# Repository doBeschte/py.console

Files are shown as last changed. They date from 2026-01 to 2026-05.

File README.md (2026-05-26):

# py.console
A gaming console based on a Raspberry Pi 5 and python games with 5 bluetooth-controllers
I designed the 3D-printed parts in Fusion360, the schematics and the PCB in KiCAD.

# HARDWARE

## CONSOLE

Console rendering

The console is based on a Raspberry Pi 5. The 3D-printed housing (12cm x 12cm) includes two parts. The main part holds all the components and electronics.
The top view looks like this:
Bildschirmfoto 2026-01-09 um 21 03 50

On the left side of this picture the Raspberry Pi will be mounted using four pieces that fit into its mounting holes. The HDMI-Ports and the USB-C-Ports are accessible from the back side of the console.
On the sides I designed some holes for the air outlet of the device. 
Bildschirmfoto 2026-01-09 um 20 36 10

On the front are two holes for a USB port and a boot push button. 
The USB port is connected to the USB port of the Raspberry Pi. It will be used to connect a USB stick with the .py game files.
The wires of the push button are connected to the two pins next to the battery connector on the Raspberry Pi to act like the integrated button.
The button has an integrated LED that is connected to GPIO13 with a resistor in series to be enabled when the device is operating.
An active buzzer is connected to GPIO18 to make a sound when booting or starting a game. It is placed in the hole of the case.

The other housing part is the top cover.
Bildschirmfoto 2026-01-09 um 21 09 07

It is mounted with two screws on the front and round pieces that fit into holes in the main part at the back.
Bildschirmfoto 2026-01-09 um 21 11 52

I will use the Raspberry Pi active cooler that takes air through the holes in the top cover.

https://github.com/user-attachments/assets/2c3ed64f-fc42-457b-9e3d-2fc4b27291a0

*This video shows how the mounting will work*

## CONTROLLERS

The controllers are more complicated as they are smaller and include more components.
I build five of them because a lot of things are shipped in five or ten, including PCBs, Joysticks, buttons, batteries etc. .

Bildschirmfoto 2026-01-14 um 21 28 14

The rendering doesn't include the joystick because I don't print it by myself.

Bildschirmfoto 2026-05-26 um 19 56 19

Bildschirmfoto 2026-01-06 um 15 12 12

The microcontroller is a XIAO-ESP32-C3 that has BLE and a battery charger and it is small. Its USB-C port is the charging port of my controller.

At the left side is a tipical thumb joystick and at the right side two buttons. They are connected to inputs on the ESP32 and GND.
Around the PCB are 20 "PL9823" LEDs. They need 5 volts which the ESP32 doesn't deliver. So, I use a little boost converter from the battery cell to five volts and a 74125 level shifter (with a 330Ω resistor) for the data. A MOSFET turnes the boost converter off when the ESP32 is in DeepSleep.
Two capacitors deliver high current for the LEDs for a short time.
The battery voltage is measured by splitting it in half using two resistors 1MΩ

The device is 12cm x 5cm, rounded at the sides and around 26mm thick. The case is made like the one of the console, but the cover is at the opposite side. The PCB is held between these two parts.
The main part holds the battery in the middle and the "keycaps" at the right side OF THE DEVICE.
Bildschirmfoto 2026-01-06 um 18 56 03

The "keycaps" just fit into their holes and have a margin to prevent falling out.
Bildschirmfoto 2026-01-06 um 18 56 38

The cover is screwed into the main case at the sides. It holds the PCB at the edges, under the joystick and under the keys for pressure, leaving a bit of space for the solder joints.

The PCB in my Renderings does not already contain all of the parts and some are just visible as pin headers:

Bildschirmfoto 2026-05-26 um 20 54 24

The following picture shows the mounted PCB inside the case. It might look wrong at the sides (little space) but it isn't.

Controller Rendering

## BOM

CONSOLE:

• Raspberry Pi 5, 4GB RAM  -  / 

• Power supply for Pi 5  -  / 

• Raspberry Pi 5 active cooler  -  /

• USB-A port  -  /

• push button, 16mm mounting hole  -  /

• active buzzer, 24mm Ø  -  /

• 330Ω resistor  -  /

• microSD-card  -  /

TOTAL PRICE CONSOLE: / (I will buy everything by myself)

CONTROLLERS:

• 5pcs custom PCB, 112mm*46mm  -  5,16€

• 5pcs Seeed Studio XIAO-ESP32-C3  -  33,33€

• 5pcs thumb joystick  -  0,87€

• 10pcs silent push button, 8*8mm  -  5,62€

• 10pcs LiPo battery, 30mm* 40mm* 5mm  -  16,88€

• 5pcs voltage regulator  -  7,50€

• 5pcs 74125 level shifter  -  5,04€

• 5pcs 330Ω resistor  -  / (I have them)

• 10pcs 1MΩ resistor  -  / (also them :D )

• 10pcs 100nF capacitor  -  0,87€

• 5pcs polarized capacitor  -  0,87€

• 100pcs PL9823 LED  -  5,50€

• 5pcs MOSFET (IRLZ44N)  -  4,60€

TOTAL PRICE 5 CONTROLLERS: 85,55€

# SOFTWARE

## CONSOLE

The console uses the Raspberry Pi Desktop. After booting, a menu appears. It shows python files saved on the external USB stick and uses pygame for the graphics.
The idea behind this project: All of the other software are some python games on a USB stick. I can code them by myself or download them from the internet - as many as I want!

## CONTROLLERS

The controllers are coded in C++ and use ESP32 bleGamepad library. They use DeepSleep to be shut down by pressing the joystick for 5 seconds or by inactivity. Pressing the Joystick will wake the ESP32 up.
The code includes a lot of animations for the LEDs, using fastLED library. The battery level is calculated using the measured battery voltage and a table from the web. It is sent every 20 seconds to the connected device and displayed on the LEDs when starting and if it is under 20%.

# cart screenshots

**Please note that i will only buy the selected items.**

Bildschirmfoto 2026-01-17 um 15 13 49
Bildschirmfoto 2026-01-17 um 15 13 39
Bildschirmfoto 2026-01-17 um 15 13 28
Bildschirmfoto 2026-01-17 um 15 13 10

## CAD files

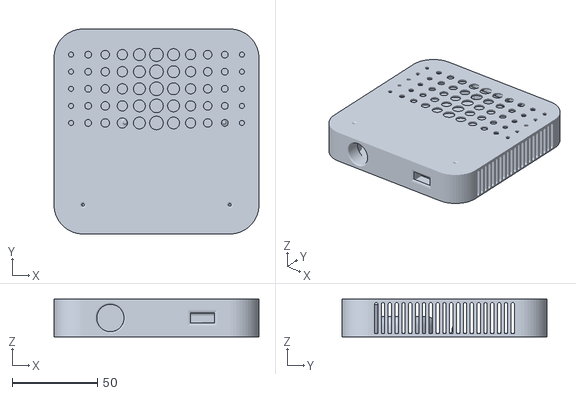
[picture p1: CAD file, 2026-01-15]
py_console/Hardware/console/Console_complete.stl
120.0 x 120.0 x 22.0

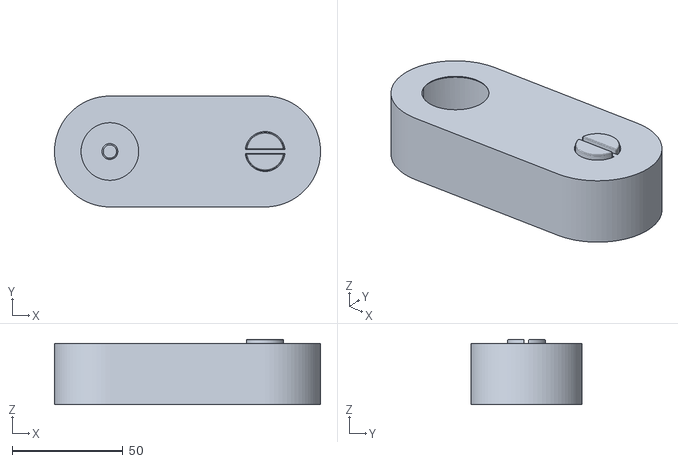
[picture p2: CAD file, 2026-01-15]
py_console/Hardware/controller/Controller_complete.stl
120.0 x 50.0 x 29.5

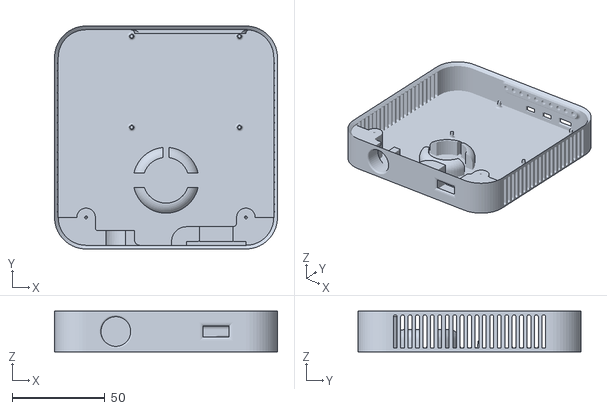
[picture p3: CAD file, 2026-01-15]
py_console/Hardware/console/main_part.stl
120.0 x 120.0 x 22.0

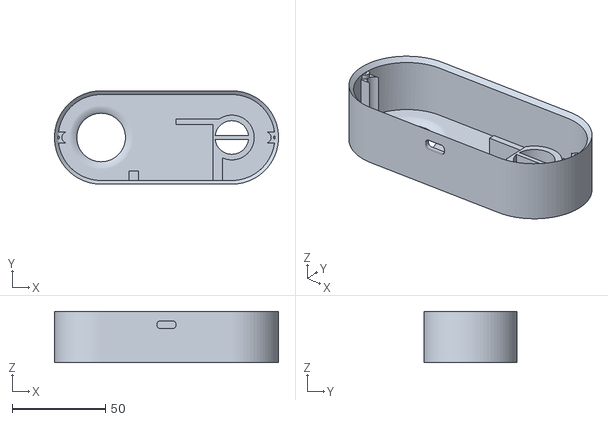
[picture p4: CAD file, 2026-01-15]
py_console/Hardware/controller/main_part.stl
120.0 x 50.0 x 27.5

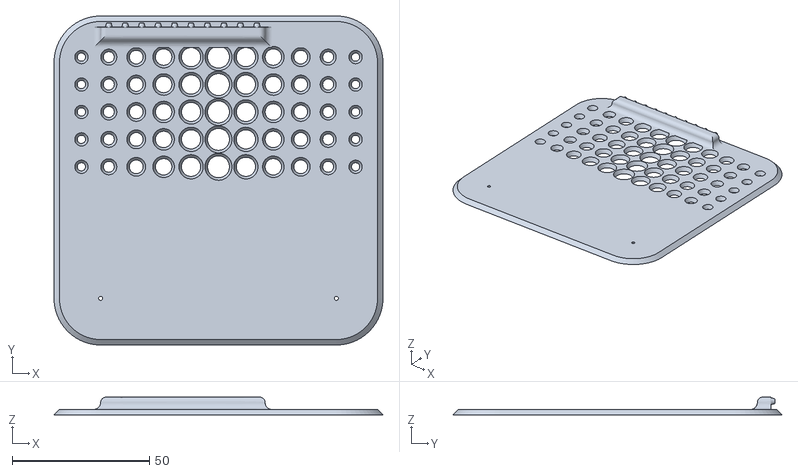
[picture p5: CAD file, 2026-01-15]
py_console/Hardware/console/console_cover.stl
120.0 x 120.0 x 6.50

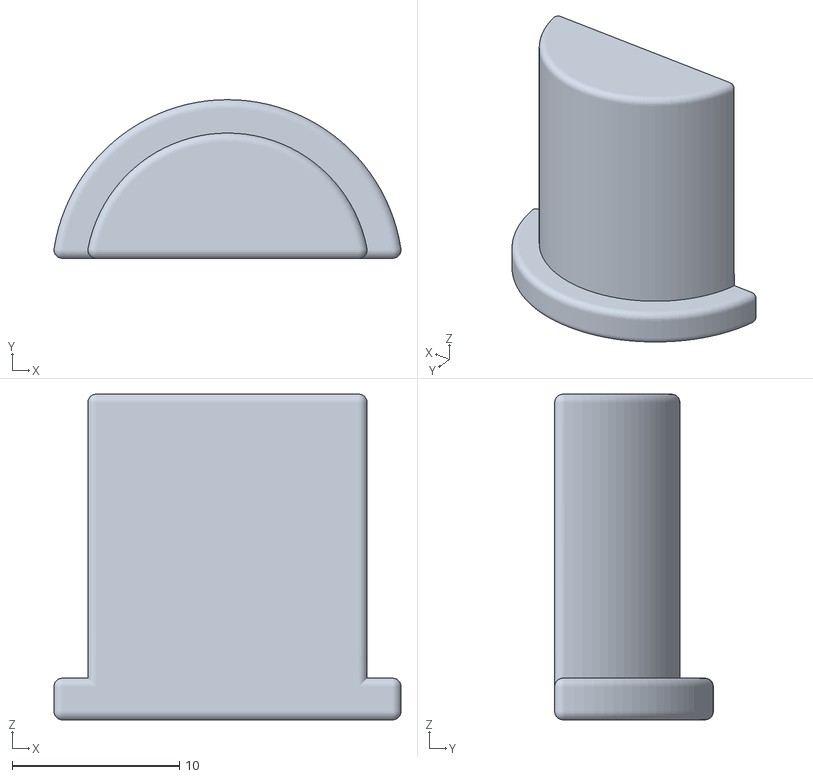
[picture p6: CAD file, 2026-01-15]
py_console/Hardware/controller/keycap.stl
20.8 x 9.50 x 19.5

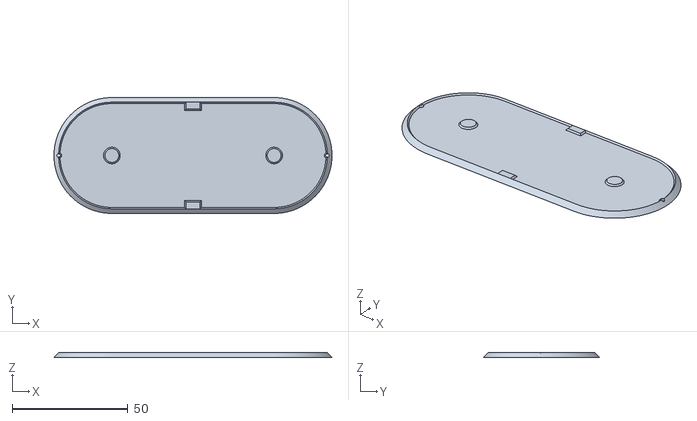
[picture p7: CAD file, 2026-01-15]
py_console/Hardware/controller/cover.stl
120.0 x 50.0 x 2.00

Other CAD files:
py_console/Hardware/console/console_cover.f3d
py_console/Hardware/console/console_main_part.f3d
py_console/Hardware/controller/Controller cover.f3d
py_console/Hardware/controller/Controller_keycap.f3d
py_console/Hardware/controller/controller_main_part.f3d

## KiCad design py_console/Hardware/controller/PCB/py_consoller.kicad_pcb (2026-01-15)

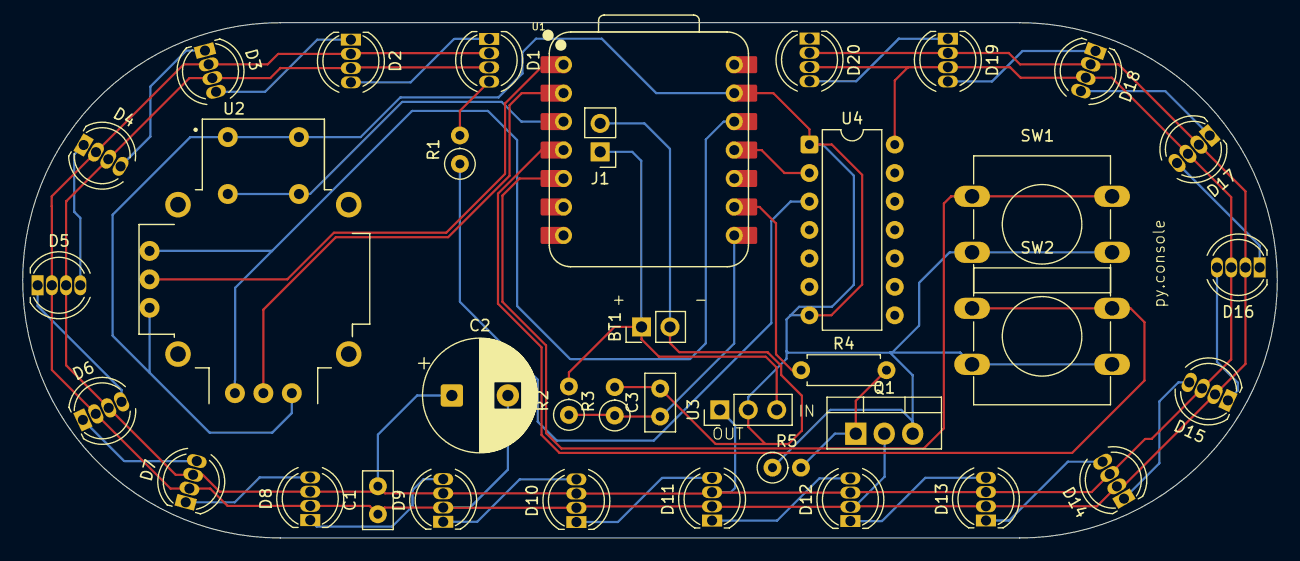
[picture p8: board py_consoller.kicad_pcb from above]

Board: 2 copper layers, 112.0 x 46.0 mm, 37 parts (0 on the bottom side), 35 nets.

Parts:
BT1: Battery_Cell; PinHeader_1x02_P2.54mm_Vertical
C1, C3: C; C_Disc_D5.0mm_W2.5mm_P2.50mm
C2: C_Polarized; CP_Radial_D10.0mm_P5.00mm
D1, D2, D3, D4, D5, D6, D7, D8, D9, D10, D11, D12, D13, D14, D15, D16, D17, D18, D19, D20: PL9823; LED_D5.0mm-4_RGB
J1: Conn_01x02; PinHeader_1x02_P2.54mm_Vertical
Q1: IRLZ34N; TO-220-3_Vertical
R1: 330Ω; R_Axial_DIN0207_L6.3mm_D2.5mm_P2.54mm_Vertical
R2, R3, R5: R; R_Axial_DIN0207_L6.3mm_D2.5mm_P2.54mm_Vertical
R4: R; R_Axial_DIN0207_L6.3mm_D2.5mm_P7.62mm_Horizontal
SW1, SW2: SW_Push; SW_PUSH-12mm
U1: XIAO ESP32C3; XIAO-ESP32C3-DIP
U2: JOYSTICK_W_BUTTON; XDCR_COM-09032
U3: PinHeader_1x03_P2.54mm_Vertical
U4: 74125; DIP-14_W7.62mm

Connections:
unnamed: BT1.1 (+), J1.1, R2.2, U3.3 (VIN)
unnamed: BT1.2 (-), C3.2, J1.2, Q1.3 (S), R3.2, R5.1, SW1.2, SW2.2, U1.13 (GND), U2.SW1, U2.X3, U2.Y3, U3.2 (GND), U4.1 (EN), U4.7 (GND)
unnamed: D1.4 (DIN), R1.2
unnamed: D1.2 (DO), D2.4 (DIN)
unnamed: C1.1, C2.2, D1.1 (GND), D2.1 (GND), D3.1 (GND), D4.1 (GND), D5.1 (GND), D6.1 (GND), D7.1 (GND), D8.1 (GND), D9.1 (GND), D10.1 (GND), D11.1 (GND), D12.1 (GND), D13.1 (GND), D14.1 (GND), D15.1 (GND), D16.1 (GND), D17.1 (GND), D18.1 (GND), D19.1 (GND), D20.1 (GND), Q1.2 (D)
unnamed: C1.2, C2.1, D1.3 (VDD), D2.3 (VDD), D3.3 (VDD), D4.3 (VDD), D5.3 (VDD), D6.3 (VDD), D7.3 (VDD), D8.3 (VDD), D9.3 (VDD), D10.3 (VDD), D11.3 (VDD), D12.3 (VDD), D13.3 (VDD), D14.3 (VDD), D15.3 (VDD), D16.3 (VDD), D17.3 (VDD), D18.3 (VDD), D19.3 (VDD), D20.3 (VDD), U3.1 (VOUT), U4.14 (VCC)
unnamed: D2.2 (DO), D3.4 (DIN)
unnamed: D3.2 (DO), D4.4 (DIN)
unnamed: D4.2 (DO), D5.4 (DIN)
unnamed: D5.2 (DO), D6.4 (DIN)
unnamed: D6.2 (DO), D7.4 (DIN)
unnamed: D7.2 (DO), D8.4 (DIN)
unnamed: D8.2 (DO), D9.4 (DIN)
unnamed: D9.2 (DO), D10.4 (DIN)
unnamed: D10.2 (DO), D11.4 (DIN)
unnamed: D11.2 (DO), D12.4 (DIN)
unnamed: D12.2 (DO), D13.4 (DIN)
unnamed: D13.2 (DO), D14.4 (DIN)
unnamed: D14.2 (DO), D15.4 (DIN)
unnamed: D15.2 (DO), D16.4 (DIN)
unnamed: D16.2 (DO), D17.4 (DIN)
unnamed: D17.2 (DO), D18.4 (DIN)
unnamed: D18.2 (DO), D19.4 (DIN)
unnamed: D19.2 (DO), D20.4 (DIN)
unnamed: Q1.1 (G), R4.2, R5.2
unnamed: U1.1 (D0), U2.X2 (X_WIPER)
unnamed: U1.2 (D1), U2.Y2 (Y_WIPER)
unnamed: U1.3 (D2), U2.SW2
unnamed: SW2.1, U1.4 (D3)
unnamed: SW1.1, U1.5 (D4)
unnamed: C3.1, R2.1, R3.1, U1.8 (D7)
unnamed: R4.1, U1.9 (D8)
unnamed: U1.11 (D10), U4.2 (D)
unnamed: U1.12 (VCC_3V3), U2.X1, U2.Y1
unnamed: R1.1, U4.3 (O)

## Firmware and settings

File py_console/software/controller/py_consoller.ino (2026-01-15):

#include <BleGamepad.h>
#include <FastLED.h>
#define JOY_X_PIN 1;
#define JOY_Y_PIN 0;
#define JOY_BTN_PIN 2;
#define BTN_UP_PIN 4;
#define BTN_DN_PIN 3;
#define BATTERY_PIN 7;
#define LED_PIN 10;
CRGB leds[20];

const int CENTER_VALUE = 2048;
const int DEADZONE = 150; 

BleGamepad bleGamepad("Controller_1", "Lenz", 100); //This is just the code for controller 1, but this is the only difference.

unsigned long buttonPressedTime = 0;
unsigned long lastConnectionTime = 0;
unsigned long lastBatteryReportTime = 0;
const unsigned long SLEEP_TIMEOUT = 300000; 
const unsigned long OFF_PRESS_TIME = 5000;
const unsigned long BATTERY_INTERVAL = 20000;

struct BatteryStep { float voltage; int percentage; };
const BatteryStep batteryTable[] = {
  {4.15, 100}, {4.05, 90}, {3.97, 80}, {3.90, 70}, {3.84, 60},
  {3.79, 50},  {3.75, 40}, {3.71, 30}, {3.66, 20}, {3.60, 10},
  {3.40, 5},   {3.20, 0}
}; //I took this table from the web.

const int tableSize = sizeof(batteryTable) / sizeof(BatteryStep);

int getBatteryPercentage() {
  long sum = 0;
  for(int i=0; i<20; i++) sum += analogRead(BATTERY_PIN);
  float avgRaw = sum / 20.0;
  float voltage = (avgRaw / 4095.0) * 6.6;

  if (voltage >= batteryTable[0].voltage) return 100;
  if (voltage <= batteryTable[tableSize - 1].voltage) return 0;
  
  for (int i = 0; i < tableSize - 1; i++) {
    if (voltage <= batteryTable[i].voltage && voltage > batteryTable[i+1].voltage) {
      float diff = batteryTable[i].voltage - batteryTable[i+1].voltage;
      float weight = (voltage - batteryTable[i+1].voltage) / diff;
      return batteryTable[i+1].percentage + (weight * (batteryTable[i].percentage - batteryTable[i+1].percentage));
    }
  }
  return 0;
}

int32_t processAxis(int rawValue) {
  int delta = rawValue - CENTER_VALUE;
  if (abs(delta) < DEADZONE) return 0;
  if (delta > 0) return map(rawValue, CENTER_VALUE + DEADZONE, 4095, 0, 32767);
  else return map(rawValue, 0, CENTER_VALUE - DEADZONE, -32767, 0);
}

// the following parts are the animations for my LEDs. I had to use a template and edit it.
void showBatteryLevel() {
  int pct = getBatteryPercentage();
  int numLedsToLight = pct / 5;
  CRGB color = (pct > 20) ? CRGB::Green : CRGB::Red;
  FastLED.clear();
  for(int i = 0; i < numLedsToLight; i++) leds[i] = color;
  for(int b = 0; b <= 100; b += 2) { FastLED.setBrightness(b); FastLED.show(); delay(10); }
  delay(1000); 
  for(int b = 100; b >= 0; b -= 2) { FastLED.setBrightness(b); FastLED.show(); delay(10); }
  FastLED.clear(); FastLED.show(); FastLED.setBrightness(50); 
}

void showSearchAnimation() {
  static uint8_t hue = 0; 
  for(int i = 0; i < 20; i++) {
    leds[i] = CHSV(hue, 255, 200);
    FastLED.show();
    delay(30);
    leds[i] = CRGB::Black;
    if(bleGamepad.isConnected()) return; 
  }
  hue += 40; 
}

// I made a function for this because it is used in two cases and the animation only in one case.
void goToSleep() {
  FastLED.clear(); FastLED.show();
  esp_deep_sleep_enable_gpio_wakeup(1 << JOY_BTN_PIN, ESP_GPIO_WAKEUP_LOW_LEVEL);
  esp_deep_sleep_start();
}

void setup() {
  FastLED.addLeds<WS2812B, LED_PIN, GRB>(leds, 20);
  showBatteryLevel();
  pinMode(JOY_BTN_PIN, INPUT_PULLUP);
  pinMode(BTN_UP_PIN, INPUT_PULLUP);
  pinMode(BTN_DN_PIN, INPUT_PULLUP);
  bleGamepad.begin();
  lastConnectionTime = millis();
}

void loop() {
  bool joyBtn = !digitalRead(JOY_BTN_PIN);

  if (joyBtn) {
    if (buttonPressedTime == 0) buttonPressedTime = millis();
    if (millis() - buttonPressedTime >= OFF_PRESS_TIME) {
      for(int i = 20 - 1; i >= 0; i--) {
    int distanceFromMiddle = abs(i - (20 / 2));
    int brightness = map(distanceFromMiddle, 0, 20/2, 255, 20);
    
    leds[i] = CRGB::Red;
    FastLED.setBrightness(brightness);
    FastLED.show();
    delay(50);
    leds[i] = CRGB::Black;
    FastLED.show();
  }
  FastLED.setBrightness(50);

      goToSleep();
    }
  } else {
    buttonPressedTime = 0;
  }

  if (bleGamepad.isConnected()) {
    lastConnectionTime = millis();
    bleGamepad.setLeftThumb(processAxis(analogRead(JOY_X_PIN)), processAxis(analogRead(JOY_Y_PIN)));

    if (joyBtn) bleGamepad.press(BUTTON_1); else bleGamepad.release(BUTTON_1);
    if (!digitalRead(BTN_UP_PIN)) bleGamepad.press(BUTTON_2); else bleGamepad.release(BUTTON_2);
    if (!digitalRead(BTN_DN_PIN)) bleGamepad.press(BUTTON_3); else bleGamepad.release(BUTTON_3);

    if (millis() - lastBatteryReportTime >= BATTERY_INTERVAL) {
      bleGamepad.setBatteryLevel(getBatteryPercentage());
      lastBatteryReportTime = millis();
    }
    bleGamepad.sendReport();
  } else {
    showSearchAnimation();
    if (millis() - lastConnectionTime >= SLEEP_TIMEOUT) goToSleep();
  }
  delay(10);
}

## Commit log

2026-01-11 Update README with hardware details and BOM
    Added detailed hardware specifications and BOM for the console and controllers.
2026-01-11 Update README with hardware and software details
    Added details about the MOSFET, microSD card, and updated resistor values. Expanded software section to include information about the console and controllers.
2026-01-12 Add prices to BOM components in README
    Updated BOM section with prices for components.
2026-01-15 Update PCB dimensions in README
2026-01-16 Revise BOM with personal item notes and price updates
    Updated BOM with personal notes and removed prices for some components.
2026-01-17 Revise BOM prices and remove personal notes
    Updated BOM prices and removed personal notes.

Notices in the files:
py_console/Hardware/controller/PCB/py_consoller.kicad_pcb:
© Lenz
